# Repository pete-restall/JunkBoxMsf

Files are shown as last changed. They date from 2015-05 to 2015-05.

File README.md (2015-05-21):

# What is this ?
[JunkBoxMsf](https://github.com/pete-restall/JunkBoxMsf) is an
[MSF](http://www.npl.co.uk/science-technology/time-frequency/products-and-services/time/msf-radio-time-signal)
Radio Receiver / Clock built from parts I've had lying around in my Junk Box
for several years and put together in an extremely short amount of time.  It
is a grossly simple TRF receiver based around Microchip's
[dsPIC30F2010](http://www.microchip.com/wwwproducts/Devices.aspx?product=dsPIC30F2010)
DSC MCU - 4K of program words, 512 bytes of RAM, 30MIPS and a 10-bit ADC.

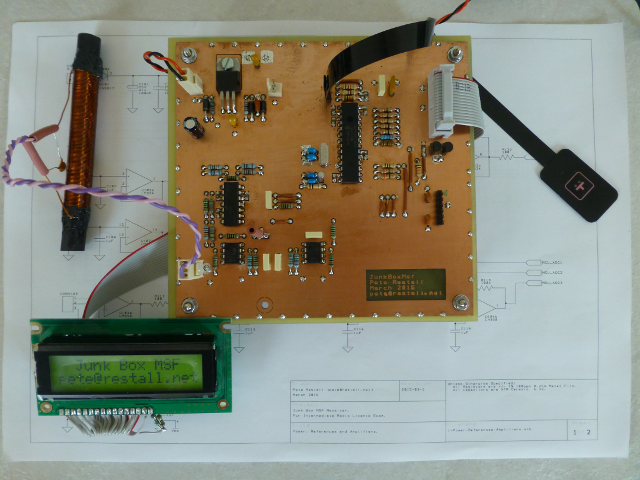
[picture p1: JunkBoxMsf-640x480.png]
JunkBoxMsf Picture


# Not the Best Parts for the Job...
The project was put together for the practical assessment of my Intermediate
Radio Licence.  I spent six weekends designing and building the hardware and
writing the majority of the firmware for this.  Ordinarily I specify and
order parts as I need them, as well as get PCBs fabricated by a professional
board house, but the turnaround was too tight for this project.  Thus, all
parts are what I had lying around in my Junk Box and not ones I'd have chosen
if I'd done this 'properly'.  The dsPIC30F2010, for example, is a motor
controller from a previous project involving stepper motors, and the PCB is
mainly through-hole and was made at home.  The whole project cost &pound;0.00,
with the membrane switch donated by Dave (thanks !)

# No TDD...?
Since submitting the project for the exam I have spent a further two weeks
adding a menu system, the clock synchronisation logic and generally testing,
tweaking, polishing and turning the device from a demonstration receiver
into a proper clock.  The initial short turnaround has meant that both the
hardware and firmware have been hacked together, thus no TDD :(

# Working Overview
This is mainly a digital project - the analogue portions are nothing more than
op-amps and a power supply.  I even omitted filtering to save time, although
there is a header on the PCB for adding a daughterboard for this purpose.
The simplicity due to the lack of filtering comes at the expense of decreased
SNR and increased aliasing, and I rely on the selectivity of the ferrite rod,
choice of sampling frequency and the fact that the MSF signal in this area is
relatively clean.  All the real magic is DSP.

The 60kHz MSF signal is decoded via an undersampling (80kHz) Goertzel Detector
algorithm, which also synchronises the on-board 32.768kHz crystal with the
MSF minute marker to achieve a time (typically) accurate to within several
tens of milliseconds of UK time.  Periodic resynchronisation is done every
few minutes or few hours (configurable via the menu system) to correct for
the tolerance and potential drift of the local crystal (30ppm) and any
intervening leap seconds that may have occurred.

The current time and date are displayed on the LCD, along with a drift
indicator and any synchronisation information such as ADC channel and whether
the last attempt was successful or not.  There is a single push-button for
menu navigation and turning on the LCD backlight.

The whole thing runs from a (nominal) 12Vdc wall wart and draws about 90mA when
receiving, 15mA in normal operation, and 11.5mA if the LCD is also turned
off.  This equates to about 140-180mW at 12V, plus wall wart losses - there
was no provision (or thought) about turning off the analogue receiver to
reduce consumption further.  The parts in my Junk Box are typically old DIPs
and not for low power operation.  The backlight on my LCD draws about 120mA.

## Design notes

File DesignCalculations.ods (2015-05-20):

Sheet: ADC Timing
MCU Instruction Frequency (Hz) | 29491200
MCU Instruction Interval (s) | 3.39084201388889E-008
Desired Sample Rate (Hz) | 80000
Sample Interval (s) | 0.0000125
Minimum Tad (ns) | 256.41 | According to DS70064E, Section 17.23, Table 17.9
 |  |  |  |  | SAMC values are in the columns below. Note that SAMC is a 5-bit wide value, so only values 0-31 are valid !
 | ADCS | Tad (s) | Tad (ns) | Adjusted Sample Interval (s) | Floor | Ceiling | Nearest | Floor Frequency / Offset |  | Ceiling Frequency / Offset |  | Nearest Frequency / Offset
!!! INVALID TAD CLOCK !!! | 1 | 3.39084201388889E-008 | 33.9084201389 | 1.20930989583333E-005 | 356 | 357 | 357 | 80139.1304347826 | -139.1304347826 | 79921.9512195122 | 78.0487804878 | 79921.9512195122 | 78.0487804878
!!! INVALID TAD CLOCK !!! | 2 | 5.08626302083333E-008 | 50.8626302083 | 1.18896484375E-005 | 233 | 234 | 234 | 80248.1632653061 | -248.1632653061 | 79921.9512195122 | 78.0487804878 | 79921.9512195122 | 78.0487804878
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

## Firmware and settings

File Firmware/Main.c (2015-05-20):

#include <xc.h>

#include "Button.h"
#include "Clock.h"
#include "Config.h"
#include "LowPowerMode.h"
#include "Mcu.h"
#include "Menu.h"
#include "Receiver.h"
#include "Screen.h"

static void initialise(void);
static void run(void);
static void showWelcome(void);
static void delayAfterWelcomeMessageShown(void);
static unsigned char eventUpdates(void);
static void runEventLoop(void);

int main(void)
{
	SET_CPU_IPL(7);
	IEC0 = 0;
	IEC1 = 0;
	IEC2 = 0;

	TRISB = 0xff;
	TRISC = 0xff;
	TRISD = 0xff;
	TRISE = 0xff;
	TRISF = 0xff;

	initialise();
	run();
	return 0;
}

static void initialise(void)
{
	lowPowerModeInitialise();
	configInitialise();
	screenInitialise();
	clockInitialise();
	receiverInitialise();
	buttonInitialise();
	menuInitialise();
}

static void run(void)
{
	SET_CPU_IPL(0);
	clockEnable();
	screenEnable();
	menuEnable();
	showWelcome();
	receiverEnable();
	clockShow();
	runEventLoop();
}

static void showWelcome(void)
{
	screenPutStringsOnBothLines(
		"  Junk Box MSF  ",
		"pete@restall.net",
		NO_CALLBACK);

	delayAfterWelcomeMessageShown();
}

static void delayAfterWelcomeMessageShown(void)
{
	unsigned int milliseconds = 0, lastInterval = 0;
	lastInterval = NOW_IN_TICKS;
	while (milliseconds < 5000)
	{
		if (TICKS_ELAPSED_SINCE(lastInterval) >= MILLISECONDS_TO_TICKS(100))
		{
			milliseconds += 100;
			lastInterval = NOW_IN_TICKS;
		}

		eventUpdates();
	}
}

static unsigned char eventUpdates(void)
{
	return
		receiverUpdate() +
		clockUpdate() +
		screenUpdate() +
		buttonUpdate() +
		menuUpdate();
}

static void runEventLoop(void)
{
	unsigned char workRemaining, noWorkRemainingCount = 0;
	while (1)
	{
		workRemaining = eventUpdates();
		if (!workRemaining)
		{
			if (++noWorkRemainingCount >= 2)
			{
				noWorkRemainingCount = 0;
				lowPowerModeGoToSleep();
			}
		}
		else
			noWorkRemainingCount = 0;
	}
}

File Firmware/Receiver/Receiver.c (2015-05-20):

#include <xc.h>
#include <string.h>

#include "../Clock.h"
#include "../Config.h"
#include "../Debug.h"
#include "../LowPowerMode.h"
#include "../Mcu.h"
#include "../Menu.h"
#include "../Receiver.h"
#include "../Screen.h"
#include "../Screen/Lcd.h"

#include "GoertzelDetector.h"
#include "MsfDecoder.h"

#if MCU_INSTRUCTION_FREQUENCY_HZ != 29491200ul
#error The values in this file need reviewing as they are calibrated to a different clock frequency !  See DesignCalculations.ods.
#endif

#define ADCON1_SIMSAM_OFF 0
#define ADCON1_SSRC_AUTO_CONVERT 7
#define ADCON1_ASAM_AUTO_START 1
#define ADCON1_FORM_SIGNED_FRACTIONAL 3

#define ADCON2_VCFG_EXTERNAL_REFERENCES 3
#define ADCON2_CHPS_CONVERT_CHANNEL0 0
#define ADCON2_SMPI_INTERRUPT_NUMBER_OF_SAMPLES(x) ((x) - 1)

#define ADCON3_ADCS_CALIBRATED_VALUE 17
#define ADCON3_SAMC_CALIBRATED_VALUE 29

#define ADCHS_CH0SA_HIGHEST_GAIN 4
#define ADCHS_CH0SA_INTERMEDIATE_GAIN 3
#define ADCHS_CH0SA_LOWEST_GAIN 2

#define ADCHS_CHANNEL_TO_STATUS_CHANNEL(channel) \
	((channel) == ADCHS_CH0SA_HIGHEST_GAIN \
		? 3 \
		: (channel) == ADCHS_CH0SA_INTERMEDIATE_GAIN \
			? 2 \
			: (channel) == ADCHS_CH0SA_LOWEST_GAIN \
				? 1 \
				: 0)

#define RECEIVER_DECODING_TIMEOUT_SECONDS (3 * 60)
#define RECEIVER_SYNCHRONISATION_TIMEOUT_SECONDS 10

ReceiverState receiverUpdate;
ReceiverStatus receiverStatus;

volatile union
{
	unsigned int asWord;

	struct
	{
		unsigned int a : 1; /* Bit locations must match in GoertzelDetectorIsr.s, too */
		unsigned int b : 1;
		unsigned int unused : 10;
		unsigned int clockSynchronised : 1;
		unsigned int synchroniseClockAtNextMinute : 1;
		unsigned int minuteMarker : 1;
		unsigned int consume : 1;
	};
} receiverBits;

static unsigned long lastReceiverSynchronisationStartedTimestamp;
static unsigned long lastReceiverDecodingCompletedTimestamp;

static UpdateStatus receiverStateDisabledAtStartup(void);
static UpdateStatus receiverStateIdle(void);
static void receiverEnableOnChannel(unsigned char channel);
static void adcDisableLowPowerMode(void);
static UpdateStatus receiverStateWaitUntilLowPowerModeExited(void);
static UpdateStatus receiverStateStartDecoding(void);
static void transitionToDebugScreen(void);
static UpdateStatus receiverStateDecoding(void);
static void receiverDisableWithNextState(ReceiverState nextState);
static UpdateStatus receiverStateFailedToDecode(void);
static UpdateStatus receiverStateTransitionFromDebugScreen(void);
static UpdateStatus receiverStateEnterLowPowerMode(void);
static void adcEnableLowPowerMode(void);
static UpdateStatus receiverStateWaitUntilLowPowerModeEntered(void);
static UpdateStatus receiverStateWaitUntilSynchronised(void);
static UpdateStatus receiverStateFailedToSynchronise(void);

#if DEBUG_RECEIVER_STUB_DATE_AND_TIME
static UpdateStatus receiverStateDebugStubDateAndTime(void);
#endif

void receiverInitialise(void)
{
	receiverUpdate = receiverStateDisabledAtStartup;
	memset(&receiverStatus, 0, sizeof(ReceiverStatus));
}

static UpdateStatus receiverStateDisabledAtStartup(void)
{
	return UpdateStatus_Idle;
}

static UpdateStatus receiverStateIdle(void)
{
	if (!config.receiver.resynchronisationUptimeInterval)
		return UpdateStatus_Idle;

	if (UPTIME_INTERVAL_SINCE(receiverStatus.lastSynchronisationCompletedTimestamp) <
	    config.receiver.resynchronisationUptimeInterval - SECONDS_TO_UPTIME(10))
		return UpdateStatus_Idle;

	receiverEnable();
	return UpdateStatus_MoreWorkQueued;
}

void receiverEnable(void)
{
	receiverEnableOnChannel(ADCHS_CH0SA_HIGHEST_GAIN);
}

static void receiverEnableOnChannel(unsigned char channel)
{
	adcDisableLowPowerMode();
	lastReceiverSynchronisationStartedTimestamp = UPTIME_NOW;
	receiverUpdate = receiverStateStartDecoding;
	receiverStatus.flagsAsPrimitive = 0;
	receiverStatus.flags.on = 1;
	receiverStatus.channel = ADCHS_CHANNEL_TO_STATUS_CHANNEL(channel);
	receiverBits.asWord = 0;
	goertzelDetectorInitialise();
	msfDecoderInitialise();

	ADCHSbits.CH0SA = channel;
	lowPowerModeDisable();
	receiverUpdate = receiverStateWaitUntilLowPowerModeExited;
}

static void adcDisableLowPowerMode(void)
{
	PMD1bits.ADCMD = 0;
	nop2();

	ADPCFGbits.PCFG5 = 1;
	ADCON1bits.SIMSAM = ADCON1_SIMSAM_OFF;
	ADCON1bits.SSRC = ADCON1_SSRC_AUTO_CONVERT;
	ADCON1bits.ASAM = ADCON1_ASAM_AUTO_START;
	ADCON1bits.FORM = ADCON1_FORM_SIGNED_FRACTIONAL;

	ADCON2bits.VCFG = ADCON2_VCFG_EXTERNAL_REFERENCES;
	ADCON2bits.CHPS = ADCON2_CHPS_CONVERT_CHANNEL0;
	ADCON2bits.SMPI = ADCON2_SMPI_INTERRUPT_NUMBER_OF_SAMPLES(16);

	ADCON3bits.SAMC = ADCON3_SAMC_CALIBRATED_VALUE;
	ADCON3bits.ADCS = ADCON3_ADCS_CALIBRATED_VALUE;

	ADCHSbits.CH0SA = ADCHS_CH0SA_HIGHEST_GAIN;

	IFS0bits.ADIF = 0;
	IEC0bits.ADIE = 1;
}

static UpdateStatus receiverStateWaitUntilLowPowerModeExited(void)
{
	if (lowPowerModeIsEnabled())
		return UpdateStatus_MoreWorkQueued;

	receiverUpdate = receiverStateStartDecoding;

#if !DEBUG_RECEIVER_STUB_DATE_AND_TIME
	ADCON1bits.ADON = 1;
#endif

	return UpdateStatus_MoreWorkQueued;
}

static UpdateStatus receiverStateStartDecoding(void)
{
	if (!menuIsVisible && config.receiver.flags.showDecodingDebug)
		screenPutStringsOnRightBothLines("MSF Sync Started", " [ Debug Mode ] ", transitionToDebugScreen);

	receiverUpdate = receiverStateDecoding;

	return UpdateStatus_MoreWorkQueued;
}

static void transitionToDebugScreen(void)
{
	screenTransitionToRight(NO_CALLBACK);
}

static UpdateStatus receiverStateDecoding(void)
{
#if !DEBUG_RECEIVER_STUB_DATE_AND_TIME
	if (UPTIME_SECONDS_SINCE(lastReceiverSynchronisationStartedTimestamp) >= RECEIVER_DECODING_TIMEOUT_SECONDS)
	{
		receiverDisableWithNextState(receiverStateFailedToDecode);
		receiverStatus.flags.decoding = 0;
		return UpdateStatus_MoreWorkQueued;
	}

	if (!receiverBits.consume)
		return UpdateStatus_MoreWorkQueued;

	receiverBits.consume = 0;
	if (receiverBits.minuteMarker)
	{
		receiverStatus.flags.decoding = 1;
		msfDecoderMinuteMarker();
	}
	else if (msfDecoderPushBits(receiverBits.a ? ~0 : 0, receiverBits.b ? ~0 : 0))
	{
		receiverStatus.flags.decoding = 0;
		receiverBits.synchroniseClockAtNextMinute = 1;
		receiverUpdate = receiverStateWaitUntilSynchronised;
		lastReceiverDecodingCompletedTimestamp = UPTIME_NOW;
	}
#else
	receiverUpdate = receiverStateDebugStubDateAndTime;
#endif

	return UpdateStatus_MoreWorkQueued;
}

static void receiverDisableWithNextState(ReceiverState nextState)
{
	ADCON1bits.ADON = 0;
	receiverUpdate = nextState;
	receiverStatus.flags.on = 0;
	receiverStatus.flags.decoding = 0;
	receiverStatus.flags.waitingForSynchronisation = 0;
	receiverStatus.channel = 0;

	if (config.receiver.flags.showCarrierDetectionDebugFlash)
		lcdBacklightOff();
}
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

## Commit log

2015-05-20 Initial Upload of JunkBoxMsf.
    [1-Power-References-Amplifiers.sch, 2-Mcu-Lcd.sch, DesignCalculations.ods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]
2015-05-21 Removed PCB / Schematics 'build' artifacts.
    [JunkBoxMsf (Bill Of Materials).csv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]
